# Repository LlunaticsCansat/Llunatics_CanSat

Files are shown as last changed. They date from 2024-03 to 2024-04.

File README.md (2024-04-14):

# Llunatics

Llunatics is a CanSat, a mini satellite that is the size of a can, designed and developed by a team formed by students of first baccalaureate in Catalonia participating in the [Esero CanSat competition](https://esero.es/cansat-2/).

The team is constructed by 5 members, each one focused on the diferent aspects of the project.

Our [Twitter](https://twitter.com/CansatLlunatics)

Our [Web Site](http://llunatics.cat/)

# Components

The microcontroller for our CanSat is an Arduino Nano Every. Because it has more Flash memory and RAM memory than a classic Arduino's, it is necessary to compile our program.

## Sensors
| Component Name | Arduino Pin | Module Pin |
|---|---|---|
| APC220 | [5V, GND, D6(RX), D7(TX)] | [VCC, GND, TXD, RXD] |
| BMP280 | [3V3, GND, A5, A4] | [VCC, GND, SCL, SDA] |
| MPU9250 | [3V3, GND, A5, A4] | [VCC, GND, SCL, SDA] |
| NEO-6M GPS | [5V, GND, RX0, TX1] | [VCC, GND, TX, RX] |
| LDR sensor | [5V, GND, A0] | |
| Buzzer | [GND, D8] | |
| SD Card Reader | [5V, GND, D13, D12, D11, D9] | [5V, GND, SCK, MISO, MOSI, CS] |

# Variables/Datas

| Name | Format | Source | Quantity |
|---|---|---|---|
| time | Unsigned Long | Arduino Power-on Timer | ms |
| temperature | Float | BMP280 | ºC |
| pressure | Float | BMP280 | pa |
| altitude | Float | BMP280 | m |
| accelerationX | Float | MPU9250 | g forces |
| accelerationY | Float | MPU9250 | g forces |
| accelerationZ | Float | MPU9250 | g forces |
| velocityRotationX | Float | MPU9250 | degrees/second |
| velocityRotationY | Float | MPU9250 | degrees/second |
| velocityRotationZ | Float | MPU9250 | degrees/second |
| magneticFieldX | Float | MPU9250 | µT |
| magneticFieldY | Float | MPU9250 | µT | 
| magneticFieldZ | Float | MPU9250 | µT | 
| Yaw | Float | MPU9250 | degrees |
| Pitch | Float | MPU9250 | degrees |
| Roll | Float | MPU9250 | degrees |
| latitude | Float | NEO-6M GPS | GCS in degrees |
| longitude | Float | NEO-6M GPS | GCS in degrees |
| rectennaVoltage | Float | Arduino analog Pin | V | 
| cansatBrightness | Float | LDR sensor | index between 0~1023  |

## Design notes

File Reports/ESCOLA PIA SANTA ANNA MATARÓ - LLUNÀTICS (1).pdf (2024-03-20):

# Informe selecció Llunàtics

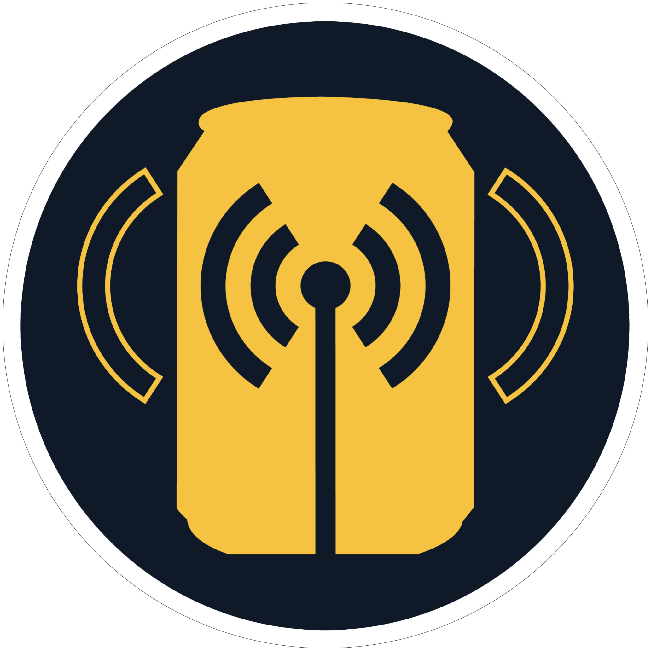
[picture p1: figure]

Equip: Llunàtics
Membres: Biel Roig Boixet, Carles Abel Moreno Fernández, Llorenç Vilà Fontbona, Pol Relaño Alsina, Yi Shu Chen Mentora: Marta Mons Genisans Centre: Escola Pia Santa Anna, Mataró, Catalunya

## 1. Missió secundària

L’objectiu de la nostra missió secundària és provar com d’eficient o útil pot ser una rectenna en dispositius que comptin amb microcomponents quan no és possible alimentar-los manualment, és a dir, si és viable com a recaptador d’energia per emmagatzemar-la i allargar el funcionament d’un dispositiu.

Una rectenna és un component que transforma les ones electromagnètiques en corrent continu mitjançant un element rectificador. És a dir, volem aprofitar les diferents radiofreqüències que pot haver-hi, tant a l’ambient, com les que enviem nosaltres per transformar-les en corrent continu.
Com que volem captar la radiació electromagnètica residual en un camp bastant ampli, hem d'amplificar el corrent rebut per la rectenna amb la finalitat de poder-la analitzar amb els components electrònics a bord. Per això, el nostre CanSat rep el subministrament elèctric d’una pila de 9v.
Tanmateix, la rectenna envoltarà el CanSat i mesurarem la seva productivitat tal i com ho hem especificat prèviament. Amb aquestes dades podrem veure si el rendiment general afirma o refuta la nostra hipòtesi. També, amb les dades de rendiment de la rectenna podríem confirmar l’existència de diferents densitats de radiofreqüències a diferents alçades.

## 2. Descripció del sistema

### 2.1. Esquema del funcionament

Per assolir les missions del CanSat hem decidit utilitzar Arduino Nano Every com el microcontrolador del sistema del CanSat, amb l’avantatge que ja tenim coneixements i experiència previs d’Arduino. Creiem que és adequat per aquest projecte, ja que dissenyar i crear dissenys amb l’Arduino és significativament més fàcil que amb altres microcontroladors. Cal destacar que hem seleccionat el microcontrolador Arduino Nano Every; que al ser un Arduino de la sèrie Nano, té l’avantatge de tenir una mida més reduïda, consumeix menys corrent, està basat en un processador més potent que altres models: l’ATMega4809, i finalment, té l’avantatge de tenir més memòria Flash (48 kB) i SRAM (6 kB), indispensables per al nostre projecte.

Complirem la missió primària amb el sensor BMP 280, que ens permet completar les dues mesures de dades de la missió primària amb un sol mòdul, amb una precisió de temperatura de ±1,0 °C i ±1 hPa a la mesura de pressió atmosfèrica.

Per estudiar i distingir l'estat del CanSat quan és a l'aire (ascendint, baixant, aterrant) fem servir el mòdul MPU 9250, un mòdul que reuneix un acceleròmetre, un giroscopi i un magnetòmetre en un sol dispositiu. També, hem inclòs una fotoresistència LDR que mesura la il·luminació exterior del CanSat; així, podrem conèixer quan s'ha separat del coet propulsor. Així doncs, amb totes aquestes dades ens és possible conèixer l'orientació amb què poder generar un model 3D del CanSat a temps real i dibuixar la trajectòria del satèl·lit.

Per facilitar la recuperació del CanSat un cop aterrat, hem afegit un mòdul GPS NEO-6N per conèixer les coordenades del CanSat i un Buzzer que s'activa després de l'aterratge per poder reproduir sons, i així, poder trobar el CanSat. No obstant, el GPS estarà prenent dades durant tot el vol i d’aquesta manera podrem traçar la trajectòria aproximada del CanSat.

De moment, la rectenna encara està en desenvolupament, però ja tenim el sistema de comprovació de viabilitat. Ara bé, per comprovar si la rectenna aconsegueix generar corrent continua, mesurarem la intensitat de corrent elèctric generat amb el sensor ACS 712 i el voltatge amb el pin analògic d'Arduino.

Per a la radiocomunicació entre el CanSat i l'estació de terra utilitzarem el mòdul APC 220. Aquest és força comú en altres projectes de CanSat, perquè té un rang de freqüència de 420 MHz fins a 450 MHz.

A més a més de la ràdio, també hem volgut escriure les dades en una targeta microSD, amb un lector de SD. Així doncs, tenim redundància a l'hora de rebre les dades, en el cas de pèrdua de connexió per ràdio.

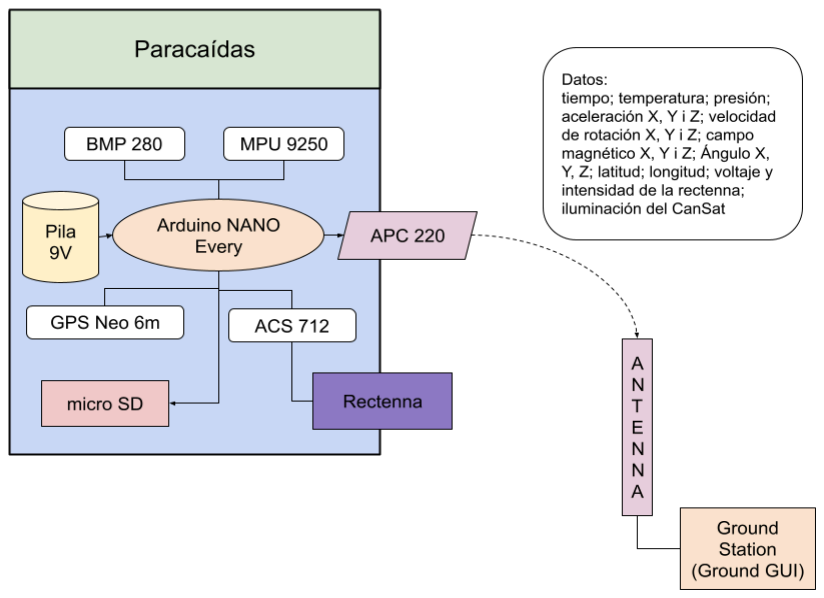
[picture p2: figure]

[Figura 1: esquema general del funcionament de CanSat]

### 2.2. Disseny elèctric

Durant el projecte hem estat duent a terme proves dels components elèctrics individualment, i la majoria d’ells funcionen correctament.

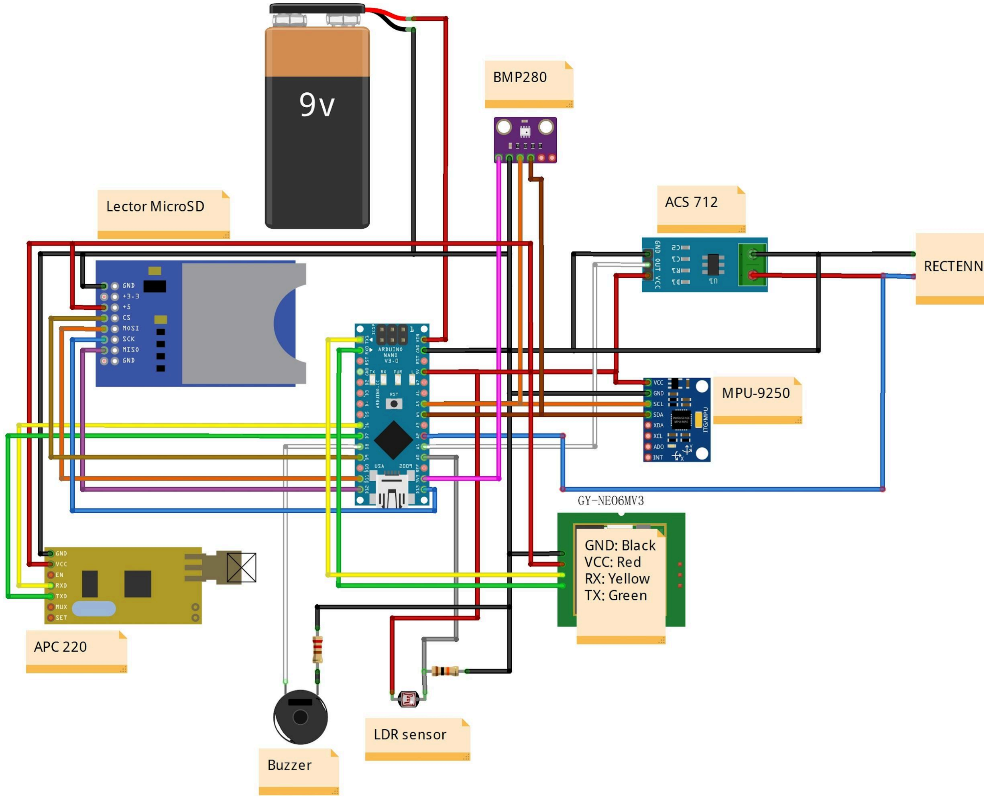
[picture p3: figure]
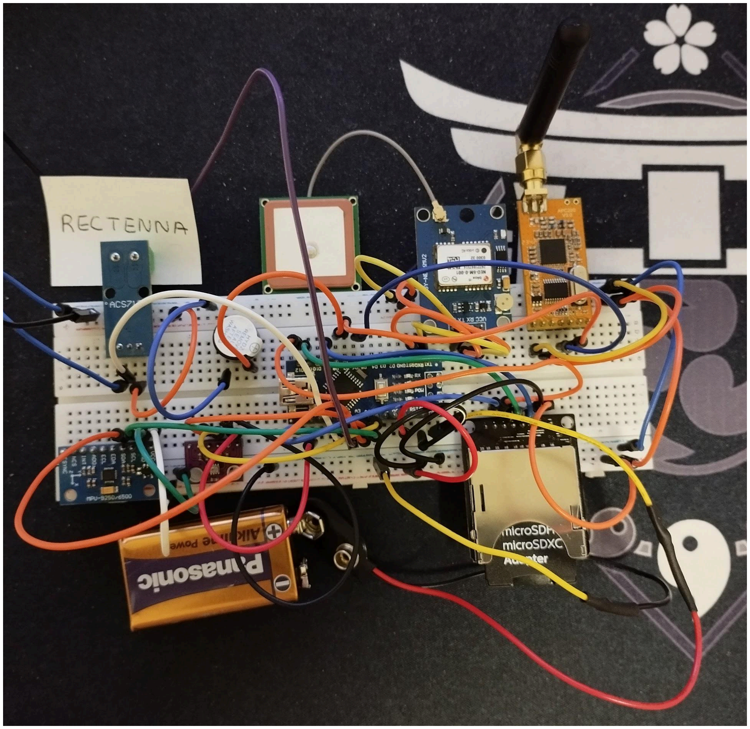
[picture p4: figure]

[Figura 2: esquema elèctric del CanSat editat en Fritzing] [Figura 3: Foto de la protoboard amb el circuit que preveiem però sense fotoresistència.]

També, hem calculat el consum aproximat de tot el sistema en la següent taula. Tenint en compte que utilitzarem una pila de 9 V i 565 mAh, el CanSat podrà estar en funcionament durant 3,2 hores aproximadament.

Components | Consum (mA)
Arduino Nano Every | 24,7
BMP 280 | 2,7 µA = 0,0027 mA
MPU 9250 | 3,7
GPS-NEO 6N | 50
ACS 712 | 10
Lector MicroSD | 50
APC 220 | 35
Buzzer | 30 (No estarà en funcionament en la majoria de temps)
LDR | 5
Total | 178,4

### 2.3. Programació i control

El programa d'Arduino que tenim preparat per al CanSat està escrit a C++ i conté les següents funcions:
- Recollir dades pels sensors (temperatura, pressió, acceleració, velocitat angular de gir, camp magnètic, intensitat i voltatge de la rectenna, etc.).
- Càlcul de Yaw, Pitch, Roll mitjançant la llibreria de MPU9250.
- Transmissió de dades per segon a l'estació de terra.
- Còpia de seguretat de les dades que van escrivint cada segon.

- Sistema de recuperació (Buzzer i GPS).

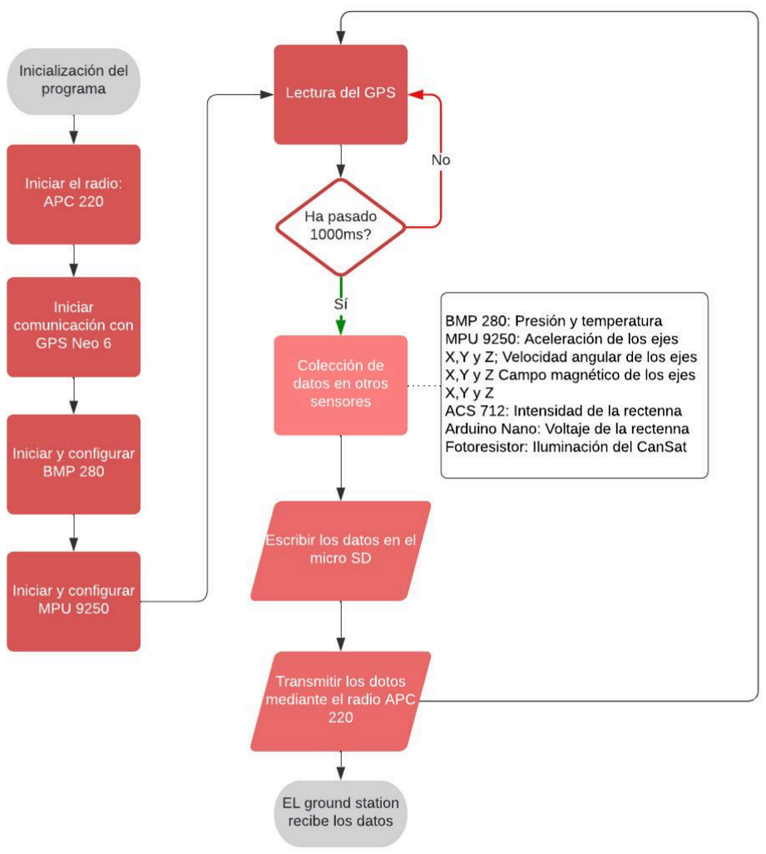
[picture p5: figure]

[Figura 4: diagrama de flux del programa de l'Arduino]

Hem utilitzat el programari Git per al control de versions dels programes. Tots els codis que hem fet servir estan penjats al repositori de Llunatics_CanSat (https://github.com/LlunaticsCansat/Llunatics_CanSat) de la plataforma GitHub com un mètode de treball col·laboratiu i seguiment de versions. I per ser el més professional possible, l'anglès ha estat el llenguatge dels codis.

### 2.4. Disseny de la carcassa

El disseny consta de quatre compartiments separats units per quatre barres roscades que brinden suport estructural, aquestes barres estan unides al cos del CanSat mitjançant insercions roscades en les etapes superior i inferior. La resta d’etapes estan subjectades amb femelles de seguretat i volanderes.
Per complir la missió secundària, a l’exterior hi podem trobar sis panells col·locats de forma radial amb un patró en espiral. Al contrari del que podria semblar, aquests no tenen rellevància estructural, sinó que solament serveixen de guia per al fil de coure que fa de rectenna.
La bateria i la majoria dels components estan ubicats a la part inferior, d’aquesta forma s’aconsegueix que el centre de gravetat sigui el més baix possible facilitant la seva estabilitat durant el descens.
Pel que fa al descens, l'etapa superior, on es troba el paracaigudes i el GPS, consta de vuit punts radials d'ancoratge de paracaigudes. Així, s’assoleix una connexió més robusta.

### 2.5. Paracaigudes

El paracaigudes està preparat per a aguantar perfectament el CanSat i reduir la seva velocitat de caiguda a uns 8 m/s. Consta d’una superfície hexagonal de 0,15 m² fabricada amb el plàstic d’una bossa de residus, i els seus fils, són filaments de pesca aguantats al paracaigudes amb cinta adhesiva i lligats a un forat.

Proves
Hem llançat el paracaigudes un total de nou vegades des del terrat d’un edifici de 7,5 metres d’alçada. En les quatre últimes proves que hem realitzat, hem recreat les següents condicions: A la primera, l’hem deixat caure fent-hi força cap endavant. El paracaigudes no es va obrir fins a la meitat del recorregut, i gairebé no va frenar la caiguda. En canvi, a la segona vegada, el paracaigudes es va obrir 1 segon més tard d’assolir l'altura màxima. Així doncs, l’acceleració va disminuint molt més i ha trigat 6 segons més que a les altres vegades. En el tercer llançamanent, vam deixar caure el paracaigudes sense cap força addicional, però aquest, no es va desplegar, ja que es va enganxar amb un tros de cinta adhesiva.
El quart cop, el paracaigudes va ser llençat sense cap mena de força, en no tenir impuls addicional, el paracaigudes no es va obrir completament fins a instants abans de tocar el terra. Tanmateix, si haguessin disposat de més espai vertical, hauríem aconseguit realitzar un aterratge controlat.

La prova de resistència de 50 N la vam fer penjant 5 kg al paracaigudes, col·locant aquest estès sobre una superfície conca, simulant un desplegament. El paracaigudes es va separar pels extrems més febles en penjar uns 3,7 kg, per això, comptem amb un recanvi al qual només se li han de lligar els fils amb un marge més generós, i una disposició de cinta de reforç més precisa. Aquest nou paracaigudes el sotmetrem a la mateixa prova, amb millor expectació que així la superi. Les dimensions romandran iguals.

### 2.6. Estació de terra

### 2.6.1. Antena

L'antena Yagi s’ha redissenyat per funcionar a una freqüència de 434 MHz (compta amb un marge des de 425 MHz fins a 469 MHz, aproximadament) amb una Gain de 9 dBd. Finalment, disposa de 4 directors i una longitud d’uns 70 cm.

Hem comprovat el seu abast, aquest cop ha superat l’abast de l’APC 220 (uns 650 m), que prèviament, ni aproximava.

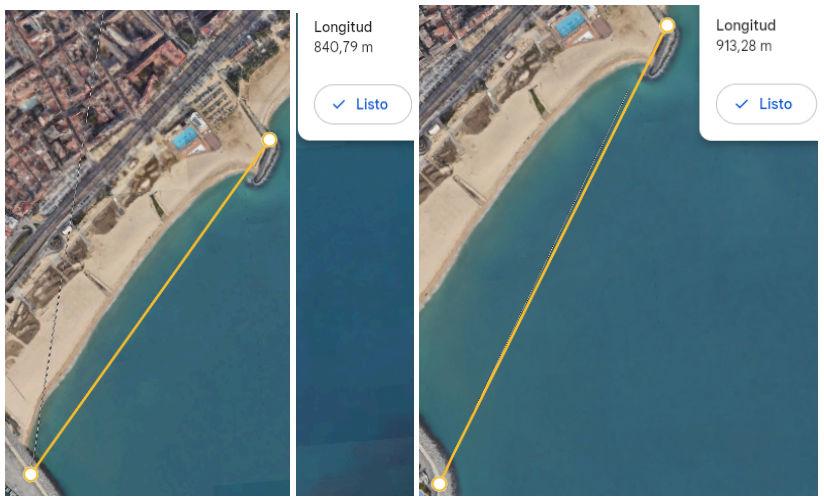
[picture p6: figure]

[Figures 5,6 i 7: Posicions i distàncies on s’han dut a terme les proves de comunicacions]

A partir del voltant dels 900 m hem començat a tenir interferències entre l’APC 220 del sistema de l’Arduino (que anirà en el CanSat) (Figura 5 i 6). En la figura 7 s’assenyala un punt on vam tenir senyal, però només vam rebre 1 dada.

### 2.6.2. Ground GUI i anàlisis de dades

També estem desenvolupant un programa de Python per estació de terra amb la finalitat de poder monitorar les dades del CanSat més visualment. Es generarà una GUI (Graphical User Interface) que anirà actualitzant, en temps reals, segons les dates rebudes per la ràdio. De moment, només hem pogut realitzar funcions molt primitives i encara l’hem de millorar i polir, com per exemple, afegir gràfiques i model 3D del CanSat. Després d’acabar el programa la penjarem en el repositori del GitHub. (https://github.com/LlunaticsCansat/Llunatics_CanSat)

Per tal de fer més fàcil i ràpid el procés d'anàlisis de dades hem desenvolupat un programa amb Python i la llibreria Pandas. Aquest recopila totes les dades de la targeta SD o els rebuts per telemetria, calcula l'altitud estimada amb la fórmula baromètrica i mostra gràfics amb la temperatura, pressió atmosfèrica i altitud calculada en vers al temps, a més de mostrar termes estadístics com la mitjana i els valors màxims i mínims.
Ens agradaria comentar una prova que vam realitzar, però que a causa d’un error de codi ja arreglat del SD, no en vam obtenir resultats. Consistia en pujar a una muntanya, en aquest cas, el turó de ca l’Amar d’Arenys de Munt (416 m), i mirar com l'altitud variava i si aquesta coincidia amb la del turó.

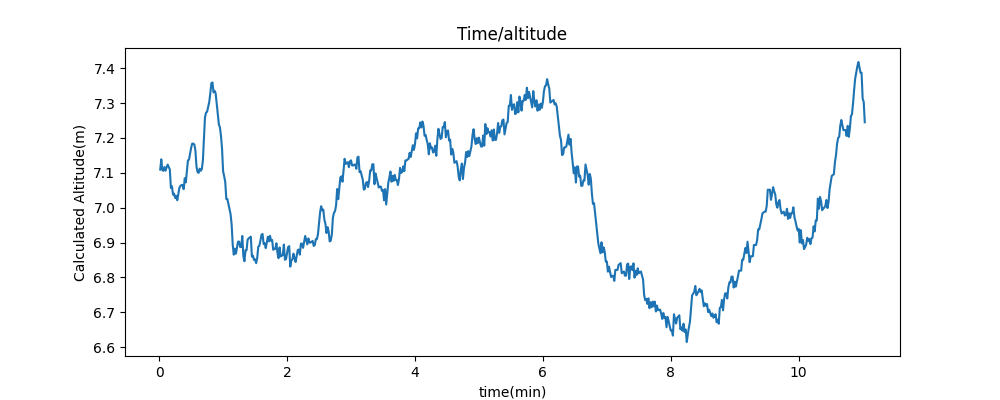
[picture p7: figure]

[Figura 8: Gràfic que relaciona l'altitud calculada amb el temps (prova estàtica)]

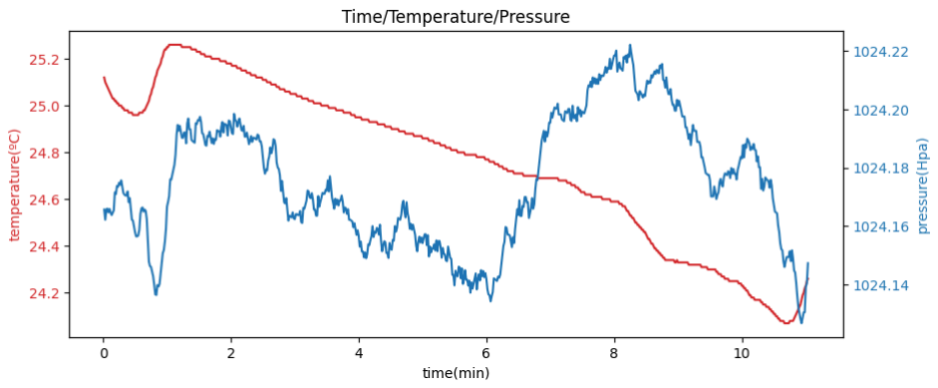
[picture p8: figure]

[Figura 9: Gràfica que representa la temperatura i la pressió en vers el temps]

## 3. Llistat de components

BMP 280

APC 220

Arduino Nano Every

Pila 9 V

MPU 9250

GPS-NEO 6N

ACS 712

Lector MicroSD

Buzzer

LDR

## 4. Valoració impacte mediàtic

Per la part de difusió del nostre projecte, hem creat una web pròpia, ens hem donat a conèixer en xarxes socials com Twitter (X), Instagram i TikTok, i hem contactat amb la revista mataronina “El Capgròs”, que ens va concedir una entrevista, i un article a la publicació mensual de març.
Arran de l’entrevista de la revista “El capgròs” hem obtingut una gran difusió del projecte a escala comarcal. Al nostre institut se n'ha assabentat gairebé tothom, en part, gràcies a professors que n’han fet difusió a les seves respectives classes de l’article publicat al “El capgròs”. Això, pot explicar l’augment de seguidors en poc temps a les xarxes socials com per exemple a Instagram.

Tanmateix, ens han contactat des de l’escola Vista Alegre per anar a fer una xerrada sobre el projecte a una classe de 5è de primària. I també, TV Mataró ens va contactar per concertar una entrevista que en data de redacció d’aquest informe ja s’ha dut a terme.
A més a més, amb l’ús de la xarxa social: TikTok, hem pogut anar més enllà del nostre entorn proper publicant vídeos amb més de 1000 visualitzacions fent-nos veure per gent de tot arreu.

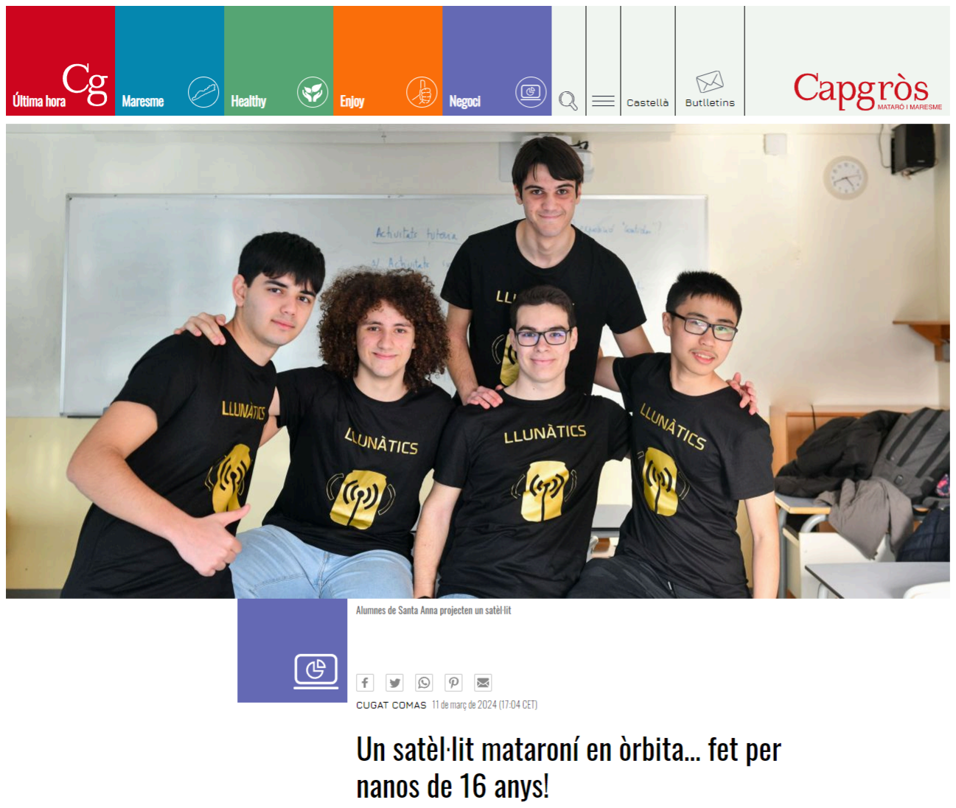
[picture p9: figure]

[Figura 10: Article de la revista “Capgròs”]

## 5. Funcionalitat

- Vídeo de funcionalitat: https://youtu.be/Gnf9duqFM0w
Concepte | Pendent | En procés | En funcionament
Lectura sensors missió primària | | | X
Lectura sensors missió secundària | | X
Transmissió de dades (Ràdio) | | | X
Guardar dades a targeta SD | | | X
Integració mecànica | | X

Paracaigudes | | X
Sistema d’alimentació | | X
Senyalització (Brunzidor) | X
Rectenna | X

## 4. Annexes

Tots els documents amb relació al disseny 3D o electrònic els podreu trobar en el nostre repositori de GitHub: https://github.com/LlunaticsCansat/Llunatics_CanSat
Per informació sobre XXSS, del nostre equip o del projecte podeu consultar la nostra pàgina web www.llunatics.cat
El vídeo de funcionalitat el podeu trobar aquí: https://youtu.be/Gnf9duqFM0w

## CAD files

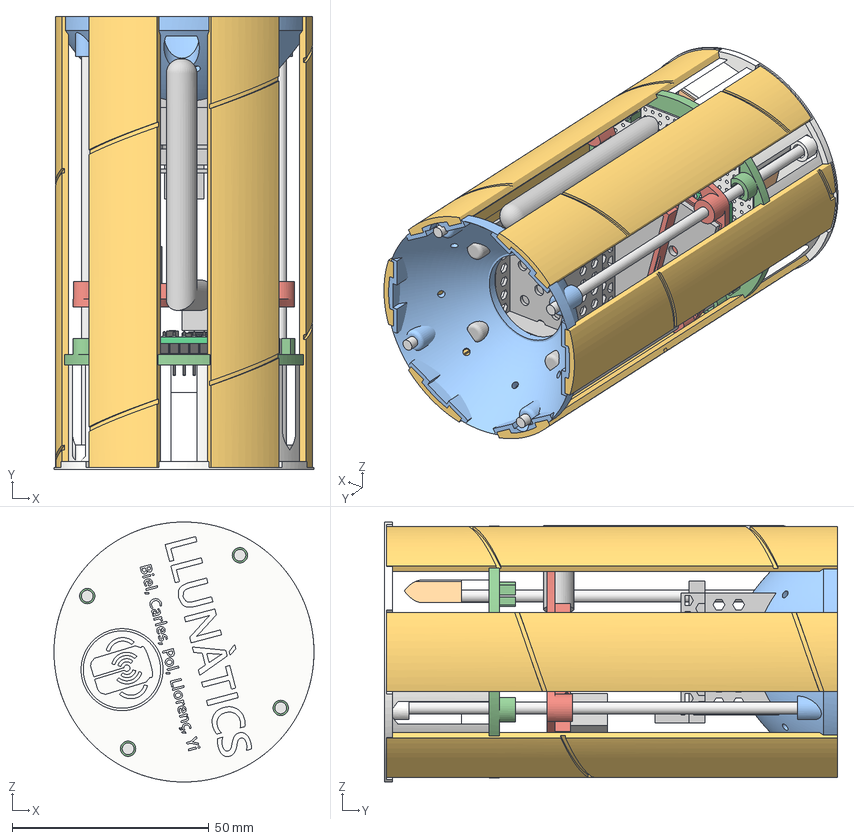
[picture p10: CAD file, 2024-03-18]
3D Design/Cansat2 v74.3mf
66.0 x 115.0 x 66.0 mm
Aguantanteenes
BASE (8)
Bateria
Carcasa 1
Carcasa 2
Carcasa 3
Carcasa 4
Carcasa 5
Carcasa 6
Conu
Crystal
Led x 4
Line x 2
NEO6M
PCB
Pin (1) (1)
Pin (1) x 5
Pin (2)
Pin x 41
PinBase x 36
Porta GPS (1)
Protoboard
REAL APC220
base
button
case
chip1
diode
lpin (1)
lpin (2)
lpin (3)
lpin (4)
lpin
pins (1) (1) (1)
pins (1) (1) x 3
pins (1) (2) x 2
pins (1) x 3
pins (10) (1)
pins (10)
pins (11) (1)
pins (11)
pins (12) (1)
pins (12)
pins (13) (1)
pins (13)
pins (14) (1)
pins (14)
pins (15) (1)
pins (15)
pins (16)
pins (2) (1) (1)
pins (2) (1) x 2
pins (2) (2)
pins (2) x 3
pins (3) (1) (1)
pins (3) (1) x 2
pins (3) (2)
pins (3) x 2
pins (4) (1) (1)
pins (4) (1) x 2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

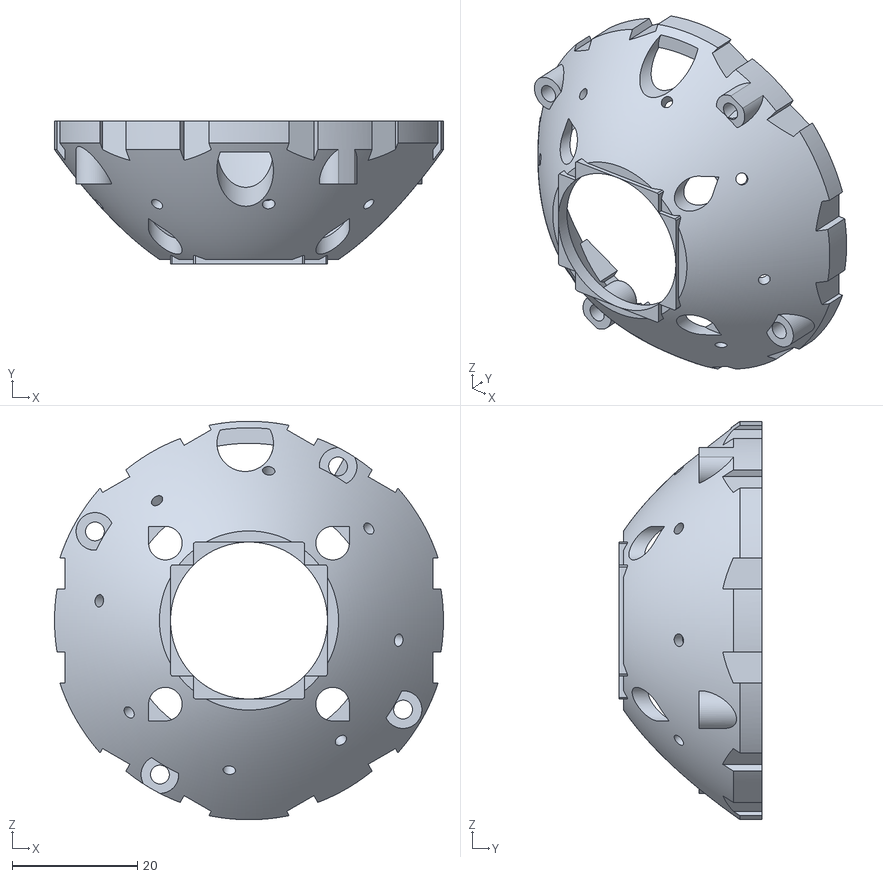
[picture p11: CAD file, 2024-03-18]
3D Design/Individual parts/Upper Recovery Bay.stl
62.0 x 22.8 x 63.5

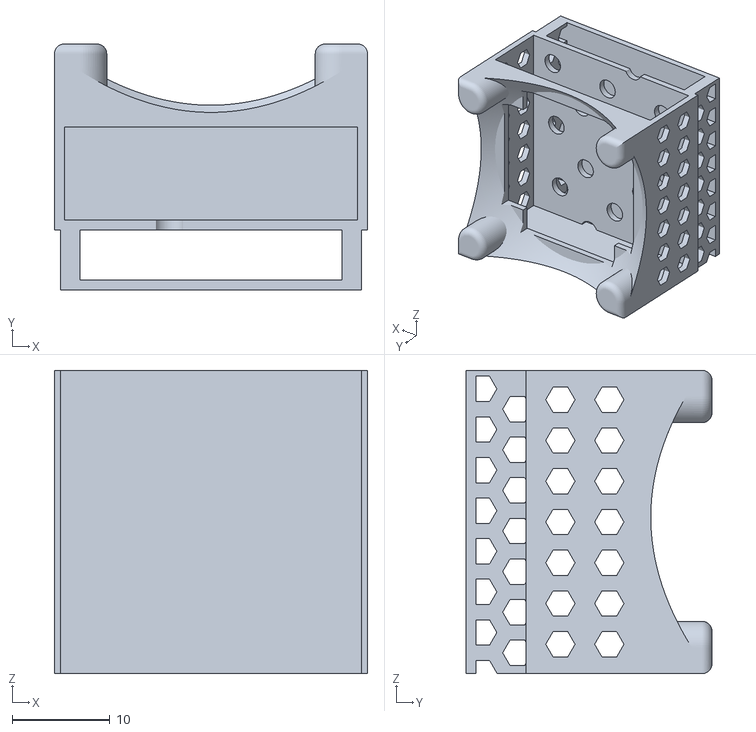
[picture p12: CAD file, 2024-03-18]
3D Design/Individual parts/Lower Recovery Bay.stl
32.0 x 25.2 x 31.0

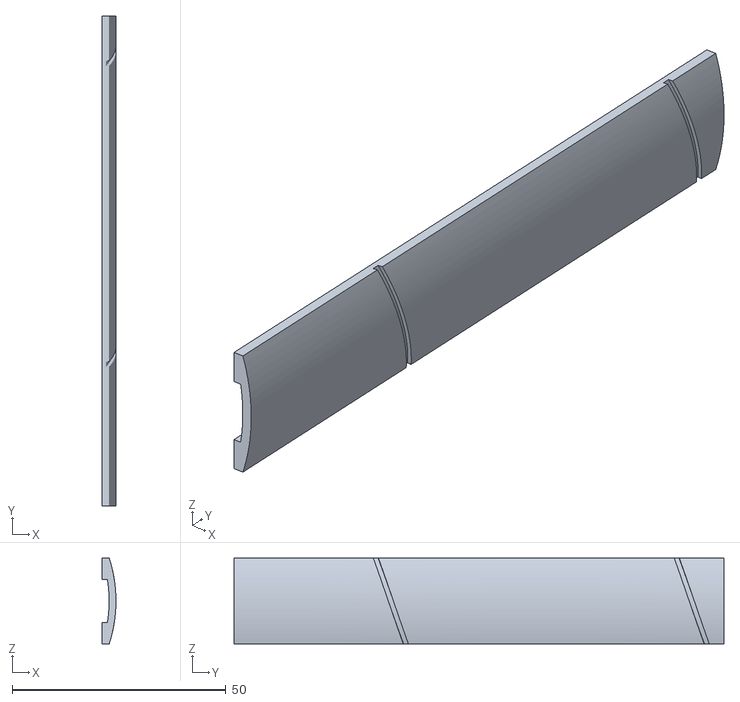
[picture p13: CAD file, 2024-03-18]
3D Design/Individual parts/Outter Shell IV.stl
3.26 x 114.5 x 20.0

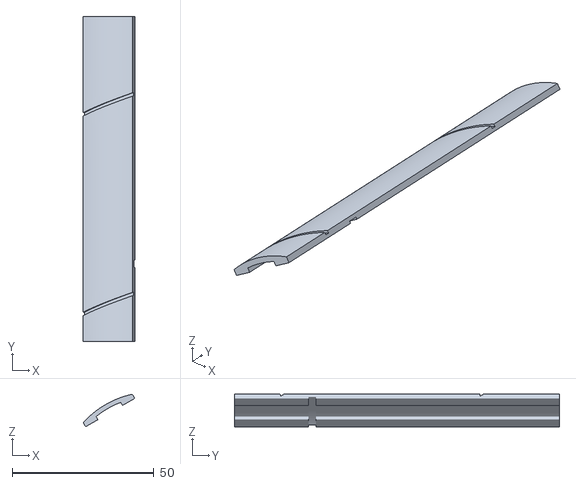
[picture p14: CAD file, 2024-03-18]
3D Design/Individual parts/Outter Shell II.stl
18.2 x 114.5 x 11.5

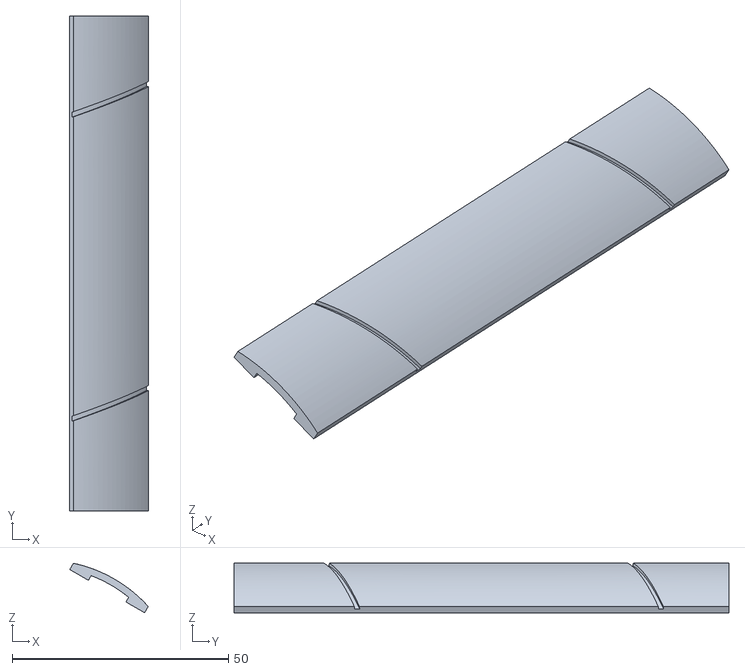
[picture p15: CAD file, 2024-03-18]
3D Design/Individual parts/Outter Shell III.stl
18.2 x 114.5 x 11.5

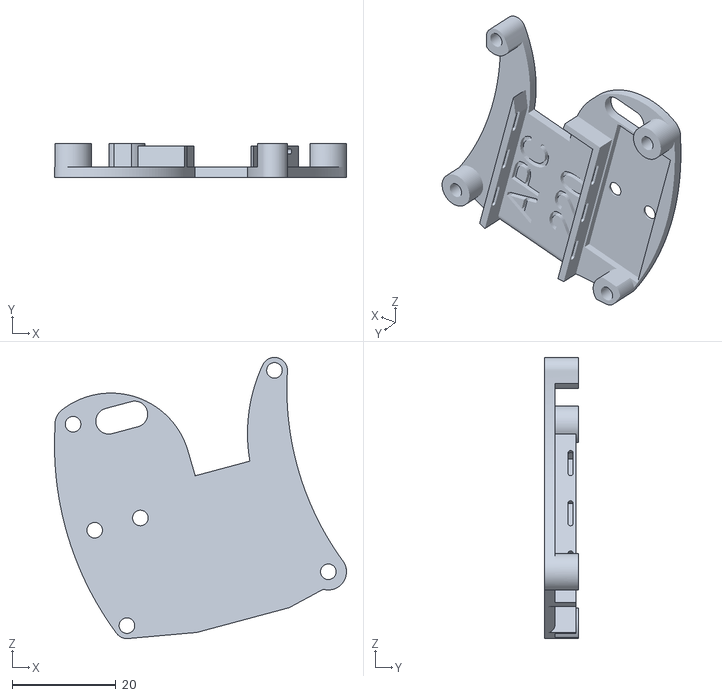
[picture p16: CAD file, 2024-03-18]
3D Design/Individual parts/Comms Bay.stl
56.2 x 6.50 x 54.1

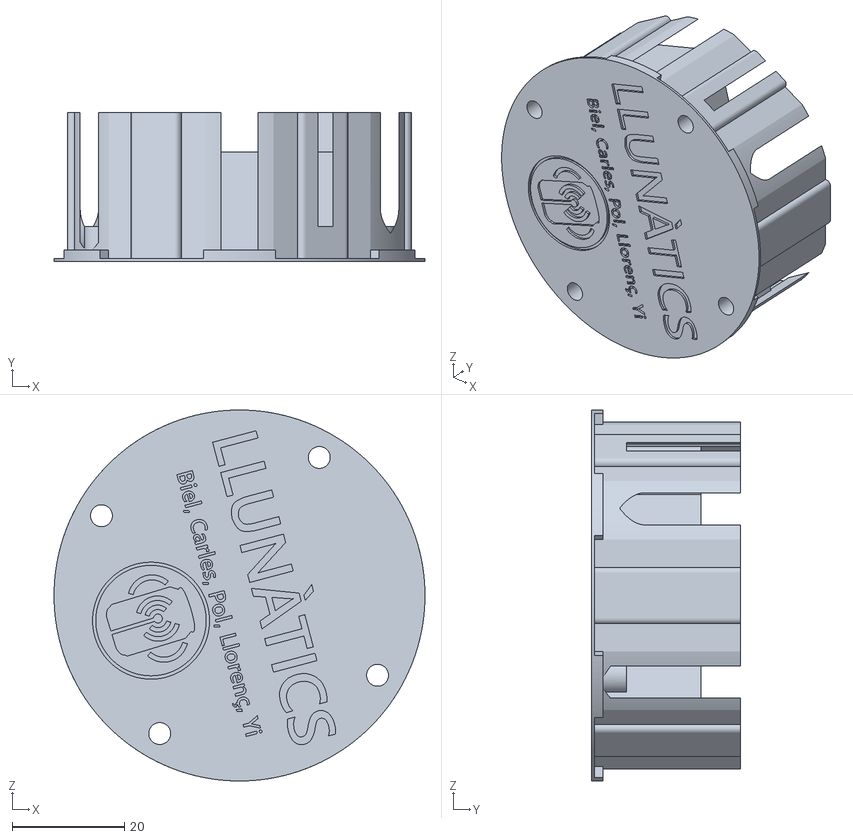
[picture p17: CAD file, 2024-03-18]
3D Design/Individual parts/Power Bay.stl
66.0 x 26.5 x 66.0

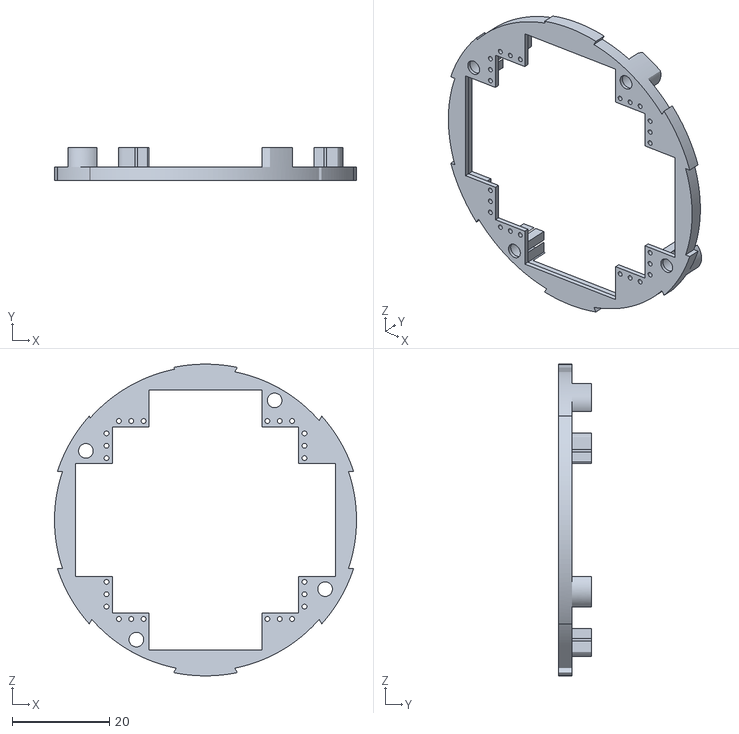
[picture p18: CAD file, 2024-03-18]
3D Design/Individual parts/Electronics Bay.stl
62.0 x 6.70 x 64.0

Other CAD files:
3D Design/Individual parts/Outter Shell I.stl
3D Design/Individual parts/Outter Shell V.stl
3D Design/Individual parts/Outter Shell VI.stl

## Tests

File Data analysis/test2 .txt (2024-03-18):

1000,25.12,102416.57
2000,25.10,102416.22
3000,25.09,102416.58
4000,25.08,102416.60
5000,25.07,102416.47
6000,25.06,102416.59
7000,25.05,102416.47
8000,25.04,102416.38
9000,25.03,102416.46
10000,25.03,102416.54
11000,25.02,102417.16
12000,25.02,102417.10
13000,25.01,102417.38
14000,25.01,102417.35
15000,25.00,102417.49
16000,25.00,102417.42
17000,25.00,102417.57
18000,24.99,102417.36
19000,24.99,102417.14
20000,24.98,102417.08
21000,24.98,102417.05
22000,24.98,102417.05
23000,24.98,102417.19
24000,24.97,102416.82
25000,24.97,102416.96
26000,24.97,102416.58
27000,24.97,102416.22
28000,24.96,102416.19
29000,24.96,102415.99
30000,24.96,102415.79
31000,24.96,102415.65
32000,24.96,102415.65
33000,24.96,102415.68
34000,24.97,102415.88
35000,24.97,102416.42
36000,24.97,102416.61
37000,24.97,102416.64
38000,24.98,102416.50
39000,24.98,102416.57
40000,24.99,102416.52
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

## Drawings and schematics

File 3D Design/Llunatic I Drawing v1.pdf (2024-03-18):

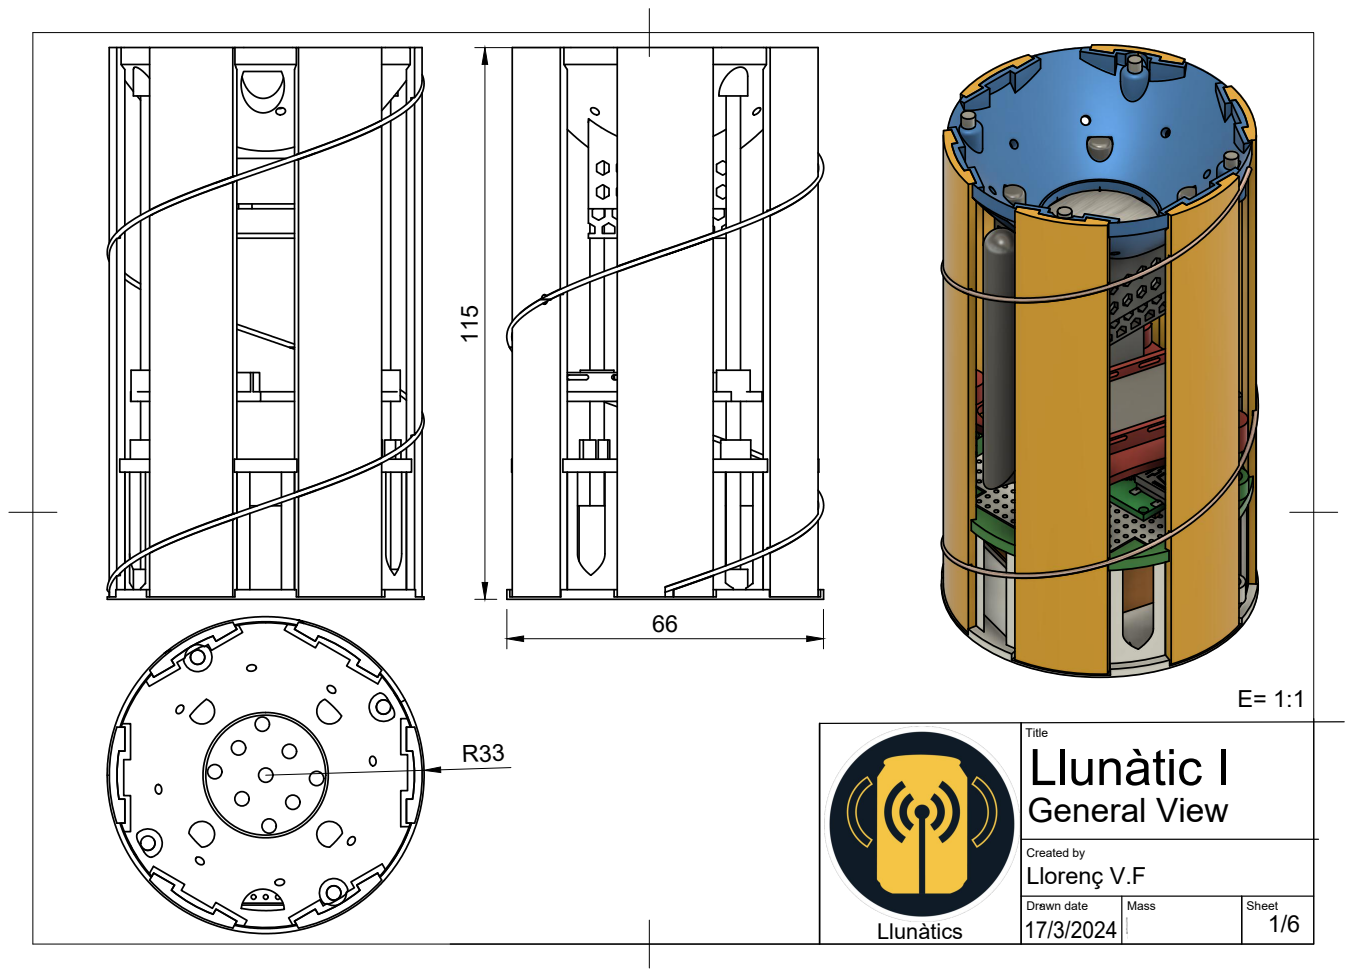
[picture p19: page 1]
Created by; Drawn date; Mass; Sheet; Llorenç V.F; General View; Llunàtic I

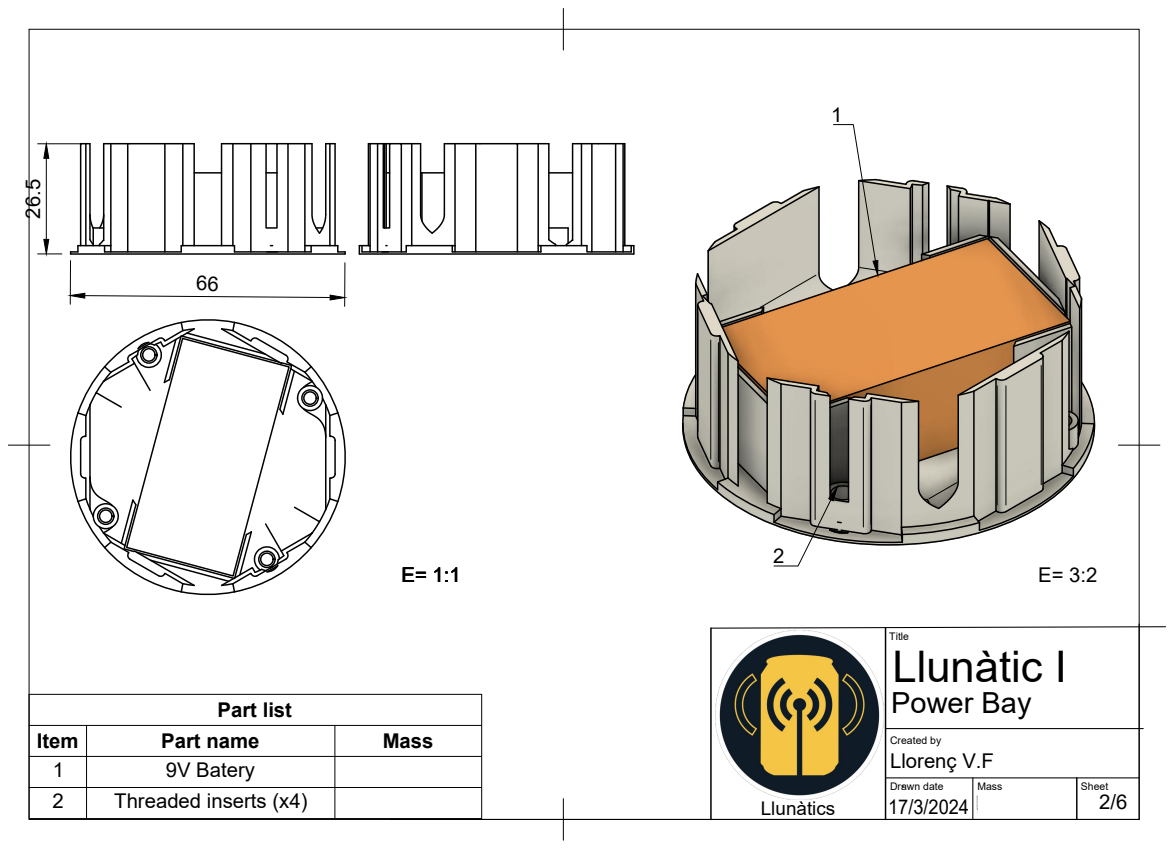
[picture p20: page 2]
Created by Llorenç V.F; Power Bay; Llunàtic I; Part list

Item | Part name | Mass
1 | 9V Batery
2 | Threaded inserts (x4)

Drawn date | Mass 143.728 g | Sheet

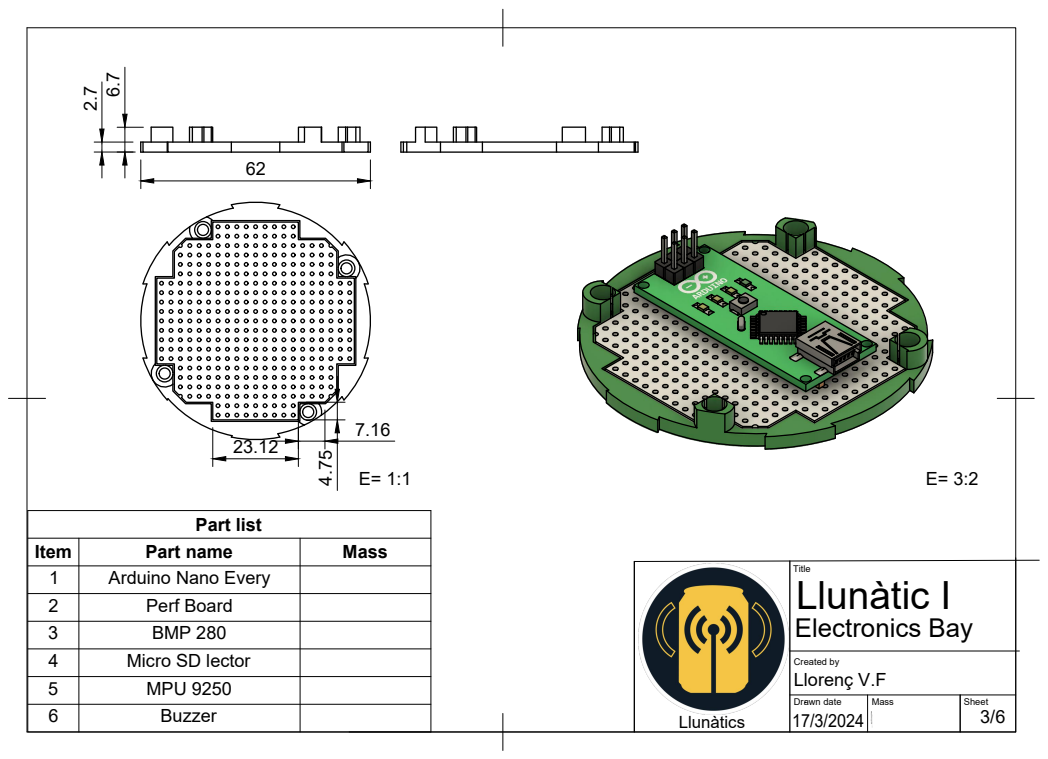
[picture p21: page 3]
Created by Llorenç V.F; Electronics Bay; Llunàtic I; Part list

Item | Part name | Mass
1 | Arduino Nano Every
2 | Perf Board
3 | BMP 280
4 | Micro SD lector
5 | MPU 9250
6 | Buzzer

Drawn date | Mass | Sheet

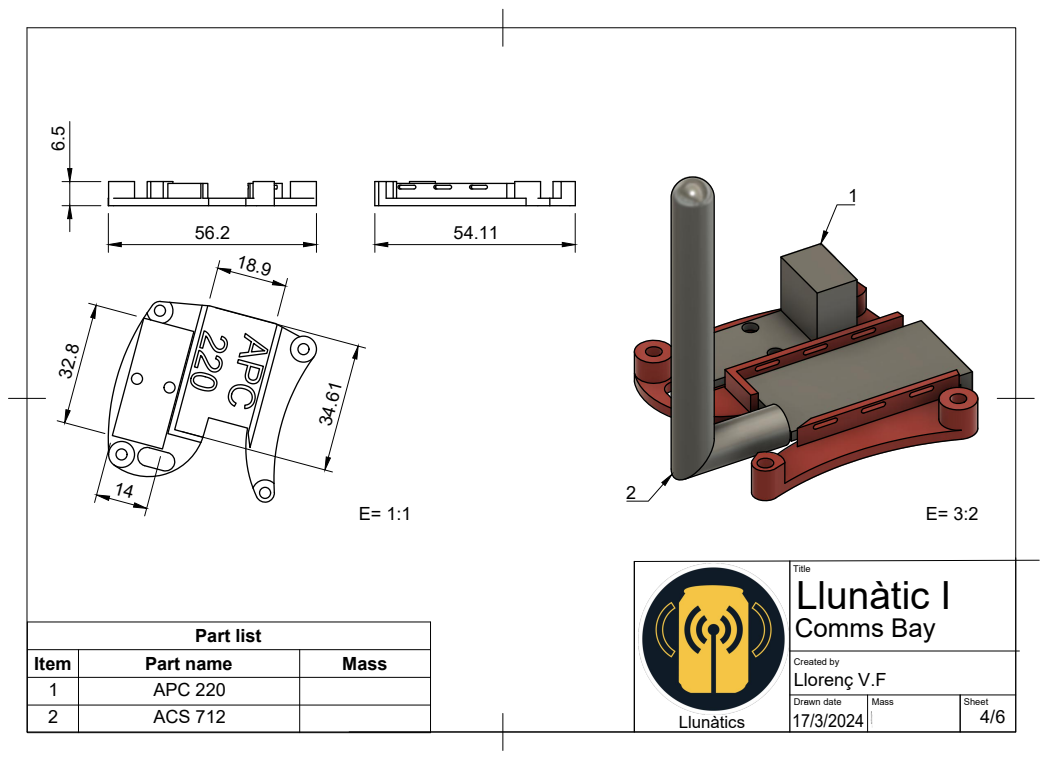
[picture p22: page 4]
Created by Llorenç V.F; Comms Bay; Llunàtic I; Part list

Item | Part name | Mass
1 | APC 220
2 | ACS 712

Drawn date | Mass | Sheet

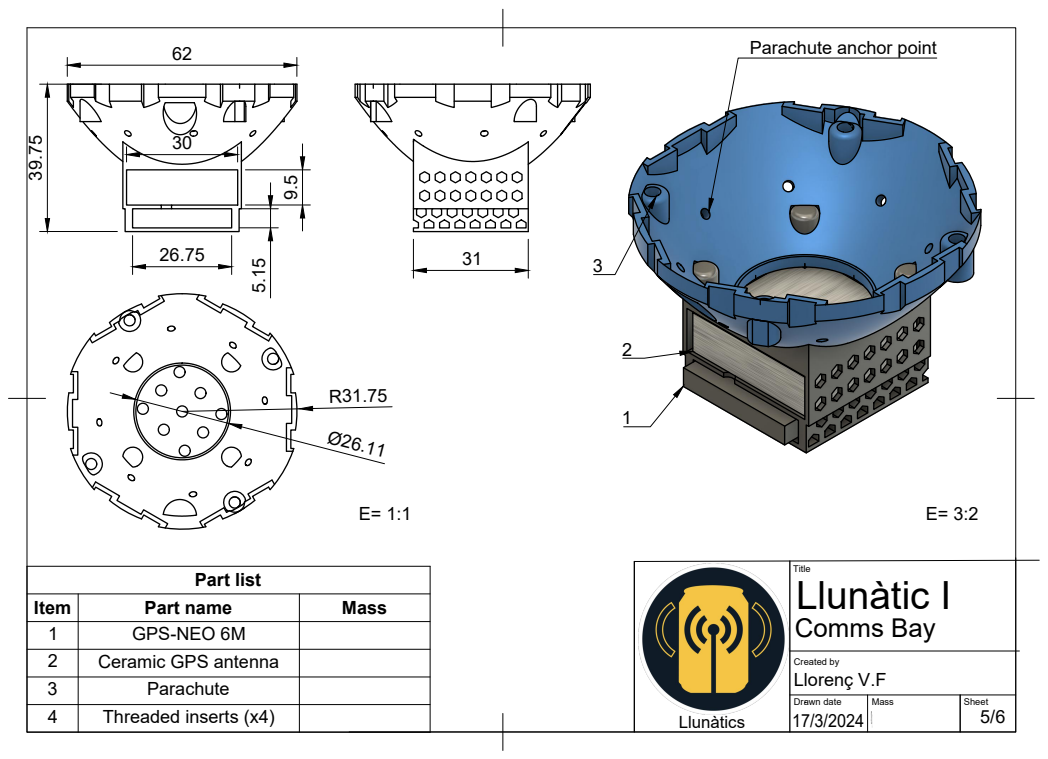
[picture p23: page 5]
Created by Llorenç V.F; Comms Bay; Llunàtic I; Part list

Parachute anchor point

Item | Part name | Mass
1 | GPS-NEO 6M
2 | Ceramic GPS antenna
3 | Parachute
4 | Threaded inserts (x4)

Drawn date | Mass | Sheet

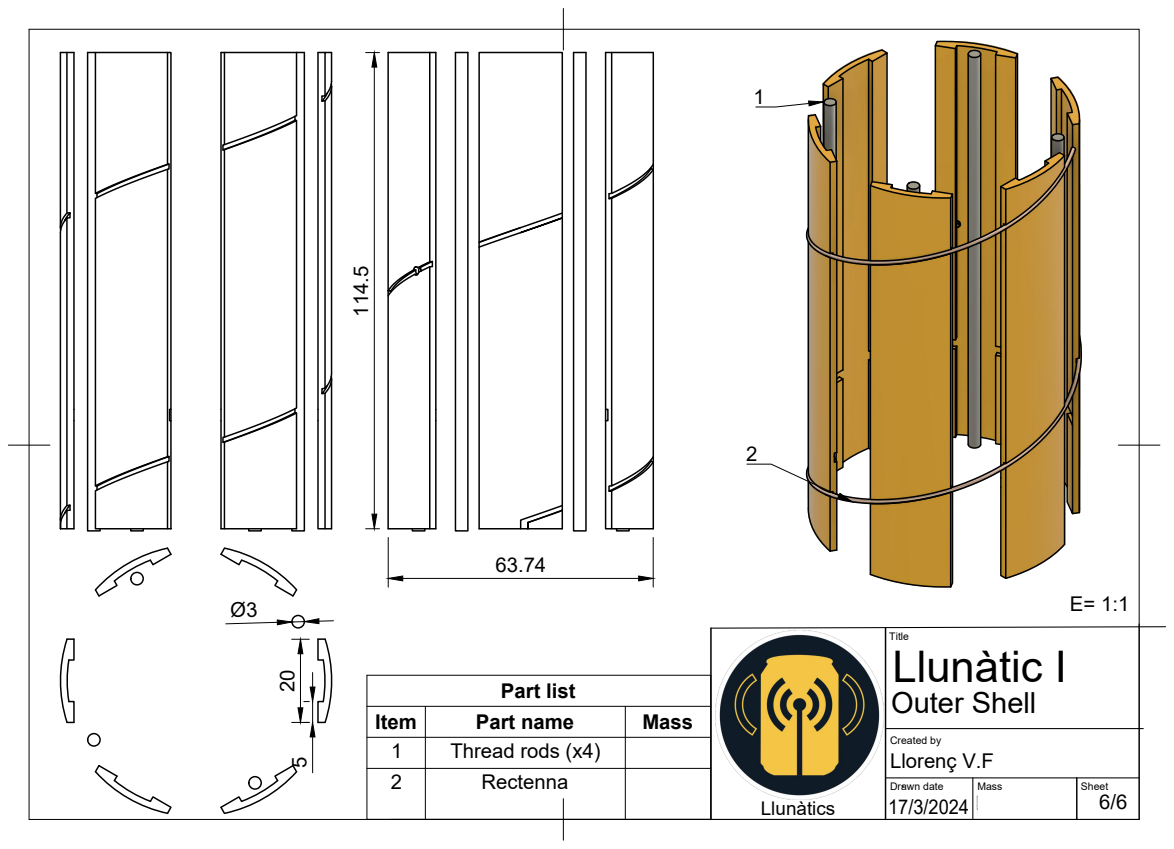
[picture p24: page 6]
Created by Llorenç V.F; Outer Shell; Llunàtic I; Part list

Item | Part name | Mass
1 | Thread rods (x4)
2 | Rectenna

Drawn date | Mass | Sheet

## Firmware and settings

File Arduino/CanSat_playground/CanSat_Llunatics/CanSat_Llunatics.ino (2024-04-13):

#include <Wire.h>             //For I2C
#include <SoftwareSerial.h>   
#include <Adafruit_Sensor.h>
#include <Adafruit_BMP280.h>  //Simplifies BMP280 temp and barometric lectures
#include <TinyGPS++.h>        //simplifies GPS lectures
#include <SD.h>               //For the SD module
#include "MPU9250.h"          //Gyroscope, compass and acceleration library



struct SensorData {               //Create a struct that contains all the dates
    unsigned long time = ULONG_MAX;
    float temperature = NAN;
    float pressure = NAN;
    float altitude = NAN;
    float accelerationX = NAN;
    float accelerationY = NAN;
    float accelerationZ = NAN;
    float velocityRotationX = NAN;
    float velocityRotationY = NAN;
    float velocityRotationZ = NAN;
    float magneticFieldX = NAN;
    float magneticFieldY = NAN;
    float magneticFieldZ = NAN;
    float Yaw = NAN;
    float Pitch = NAN;
    float Roll = NAN;
    float latitude = NAN;
    float longitude = NAN;
    float rectennaVoltage = NAN;
    float cansatBrightness = NAN;
};


const int RadioRX = 7;
const int RadioTX = 6;


TinyGPSPlus gps;

SoftwareSerial radio(RadioRX, RadioTX); // APC220: RX7, TX6

Adafruit_BMP280 bmp;
MPU9250 mpu;

File dataFile;

float latitude;
float longitude;
  
unsigned long countTime = millis();

void setup() {
  
  Serial1.begin(9600); //The GPS will be connected to Serial1 to optimize the gobal variable space
  Wire.begin();
  radio.begin(9600);
  radio.println(F("Initialitzating CanSat"));

  bmp.begin(0x76); // BMP280 Pressure and temperature sensor
  bmp.setSampling(Adafruit_BMP280::MODE_NORMAL,     /* Operating Mode. */
                  Adafruit_BMP280::SAMPLING_X2,     /* Temp. oversampling */
                  Adafruit_BMP280::SAMPLING_X16,    /* Pressure oversampling */
                  Adafruit_BMP280::FILTER_X16,      /* Filtering. */
                  Adafruit_BMP280::STANDBY_MS_500); /* Standby time. */

  mpu.setup(0x68);
  
  if (!SD.begin(9))
  {
    radio.println(F("Error at startup SD"));
    return;
  }
  
  if(!SD.exists("cansat.csv"))
  {
    dataFile = SD.open("cansat.csv", FILE_WRITE);
    if (dataFile) {
      dataFile.println("time,temperature,pressure,altitude,accelerationX,accelerationY,accelerationZ,velocityRotationX,velocityRotationY,velocityRotationZ,magneticFieldX,magneticFieldY,magneticFieldZ,yaw,pitch,roll,latitude,longitude,rectennaVoltage,cansatBrightness");
        
      dataFile.close();
    }
  }
}


void loop() {
  
  unsigned long currentTime = millis();
  
  float AccX, AccY, AccZ, GyroX, GyroY, GyroZ, MagX, MagY, MagZ, Yaw, Pitch, Roll;

  if (mpu.update()) {
    AccX = mpu.getAccX();
    AccY = mpu.getAccY();
    AccZ = mpu.getAccZ();
    GyroX = mpu.getGyroX();
    GyroY = mpu.getGyroY();
    GyroZ = mpu.getGyroZ();
    MagX = mpu.getMagX();
    MagY = mpu.getMagY();
    MagZ = mpu.getMagZ();
    Yaw = mpu.getYaw();
    Pitch = mpu.getPitch();
    Roll = mpu.getRoll();
    }

  while (Serial1.available() > 0) {
    
    if (gps.encode(Serial1.read())) {
      
      if (gps.location.isValid()) {
        
        latitude = gps.location.lat(); //Get GPS measures
        longitude = gps.location.lng();
        
        }
    }
  }

  if (currentTime - countTime >= 1000){   
    SensorData currentSensorData = CollectSensorData(currentTime, latitude, longitude, AccX, AccY, AccZ, GyroX, GyroY, GyroZ, MagX, MagY, MagZ, Yaw, Pitch, Roll);
    backUpData(currentSensorData);
    sendData(currentSensorData);
    countTime = currentTime;
  }

}


SensorData CollectSensorData(unsigned long currentTime, float currentLatidude, float currentLongitude, float AccX, float AccY, float AccZ, float GyroX, float GyroY, float GyroZ, float MagX, float MagY, float MagZ, float Yaw, float Pitch, float Roll) { //Collect dates from the sensors (exept Gps and MPU9250)

    SensorData currentSensorData;

    currentSensorData.time = currentTime; 
    currentSensorData.temperature = bmp.readTemperature(); // BMP280: Temperature
    currentSensorData.pressure = bmp.readPressure(); // BMP280: Pressure
    currentSensorData.altitude = bmp.readAltitude(1013.25); // BMP280: Altitude
    currentSensorData.accelerationX = AccX; //MPU9250
    currentSensorData.accelerationY = AccY;
    currentSensorData.accelerationZ = AccZ;
    currentSensorData.velocityRotationX = GyroX;
    currentSensorData.velocityRotationY = GyroY;
    currentSensorData.velocityRotationZ = GyroZ;
    currentSensorData.magneticFieldX = MagX;
    currentSensorData.magneticFieldY = MagY;
    currentSensorData.magneticFieldZ = MagZ;   
    currentSensorData.Yaw = Yaw;
    currentSensorData.Pitch = Pitch;
    currentSensorData.Roll = Roll;
    currentSensorData.latitude = currentLatidude; //GPS
    currentSensorData.longitude = currentLongitude;
    currentSensorData.rectennaVoltage = analogRead(A2) /1023 * 5.0; //Arduino
    currentSensorData.cansatBrightness = analogRead(A0); //Photoresistor

    return currentSensorData;
}


void backUpData(SensorData Backup){   //Writes data into the microSD

  dataFile = SD.open("cansat.csv", FILE_WRITE);

  dataFile.print(Backup.time);
  dataFile.print(F(","));
  
  dataFile.print(Backup.temperature);
  dataFile.print(F(","));
  dataFile.print(Backup.pressure);
  dataFile.print(F(","));
  dataFile.print(Backup.altitude);
  dataFile.print(F(","));

  dataFile.print(Backup.accelerationX);
  dataFile.print(F(","));
  dataFile.print(Backup.accelerationY);
  dataFile.print(F(","));
  dataFile.print(Backup.accelerationZ);
  dataFile.print(F(","));

  dataFile.print(Backup.velocityRotationX);
  dataFile.print(F(","));
  dataFile.print(Backup.velocityRotationY);
  dataFile.print(F(","));
  dataFile.print(Backup.velocityRotationZ);  
  dataFile.print(F(","));

  dataFile.print(Backup.magneticFieldX);
  dataFile.print(F(","));
  dataFile.print(Backup.magneticFieldY);
  dataFile.print(F(","));
  dataFile.print(Backup.magneticFieldZ);  
  dataFile.print(F(","));

  dataFile.print(Backup.Yaw);
  dataFile.print(F(","));
  dataFile.print(Backup.Pitch);
  dataFile.print(F(","));
  dataFile.print(Backup.Roll);
  dataFile.print(F(","));

  dataFile.print(Backup.latitude,6);
  dataFile.print(F(","));
  dataFile.print(Backup.longitude,6);
  dataFile.print(F(","));

  dataFile.print(Backup.rectennaVoltage);
  dataFile.print(F(","));

  dataFile.println(Backup.cansatBrightness);

  dataFile.close();
}



void sendData(SensorData Data){ //send data to ground station with APC220
  
  radio.print(F("Llunatics"));
  radio.print(F(","));
  radio.print(Data.time);
  radio.print(F(","));
  radio.print(Data.temperature);
  radio.print(F(","));
  radio.print(Data.pressure);
  radio.print(F(","));
  radio.print(Data.altitude);
  radio.print(F(","));
  
  radio.print(Data.accelerationX);
  radio.print(F(","));
  radio.print(Data.accelerationY);
  radio.print(F(","));
  radio.print(Data.accelerationZ);
  radio.print(F(","));

  radio.print(Data.velocityRotationX);
  radio.print(F(","));
  radio.print(Data.velocityRotationY);
  radio.print(F(","));
  radio.print(Data.velocityRotationZ);  
  radio.print(F(","));

  radio.print(Data.magneticFieldX);
  radio.print(F(","));
  radio.print(Data.magneticFieldY);
  radio.print(F(","));
  radio.print(Data.magneticFieldZ);  
  radio.print(F(","));

  radio.print(Data.Yaw);
  radio.print(F(","));
  radio.print(Data.Pitch);
  radio.print(F(","));
  radio.print(Data.Roll);
  radio.print(F(","));

  radio.print(Data.latitude,6);
  radio.print(F(","));
  radio.print(Data.longitude,6);
  radio.print(F(","));

  radio.print(Data.rectennaVoltage);
  radio.print(F(","));

  radio.println(Data.cansatBrightness);
}

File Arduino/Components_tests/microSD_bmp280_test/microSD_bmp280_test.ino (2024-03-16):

#include <SD.h>
#include<Wire.h>
#include<Adafruit_Sensor.h>
#include <Adafruit_BMP280.h>

File dataFile;
Adafruit_BMP280 bmp;

unsigned long countTime = millis();

void setup() {
  Serial.begin(9600);
  Serial.println(F("BMP280 test"));

  if (!bmp.begin()) {
    Serial.println(F("Could not find a valid BMP280 sensor, check wiring!"));
    while (1); }

  bmp.begin(0x76);
  bmp.setSampling(Adafruit_BMP280::MODE_NORMAL,     /* Modo de operaciÃ³n */
                  Adafruit_BMP280::SAMPLING_X2,     /* Temp. oversampling */
                  Adafruit_BMP280::SAMPLING_X16,    /* Presion oversampling */
                  Adafruit_BMP280::FILTER_X16,      /* Filtrado. */
                  Adafruit_BMP280::STANDBY_MS_500); /* Tiempo Standby. */

  if (!SD.begin(9))
  {
    Serial.println(F("Error at startup"));
    return;
  }
  Serial.println(F("Correctly initiated"));
      
  if(!SD.exists("datalog.csv"))
  {
      dataFile = SD.open("datalog.csv", FILE_WRITE);
      if (dataFile) {
        Serial.println("New file, Writing headers(row 1)");
        dataFile.println("Time(ms),Temperature,Pressure");
        dataFile.close();
      } else {
        Serial.println("Error creating the file datalog.csv");
      }
  }
}

void loop() {

  unsigned long currentTime = millis();

  if (currentTime - countTime >= 1000){
    
    dataFile = SD.open("datalog.txt", FILE_WRITE);
    if (dataFile){
        dataFile.print(currentTime);
        dataFile.print(","); 
      
        dataFile.print(bmp.readTemperature());
        dataFile.print(",");
      
        dataFile.println(bmp.readPressure());
      
        dataFile.close();
      
        Serial.println("finish printing");

        countTime = currentTime;

    } else {
      Serial.println("error to open the foulder");
    }
  }

  
}

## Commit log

2024-02-20 Create main.py
    The python code that analizes sensor data
2024-03-16 Update CanSat_Llunatics.ino
    fixed bug
    [CanSat_Llunatics.ino]
2024-03-16 Update CanSat_Llunatics_with_buzzer.ino
    sd card bug fixed
    [CanSat_Llunatics_with_buzzer.ino]
2024-04-13 update
    sd file name bug fixed
    [CanSat_Llunatics.ino, CanSat_Llunatics_with_buzzer.ino]
